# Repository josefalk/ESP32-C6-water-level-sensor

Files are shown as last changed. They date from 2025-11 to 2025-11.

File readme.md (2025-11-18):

# ESP32-C6 Water Level Monitoring System

Ultrasonic tank-level monitor with 
**A02YYUW sensor**, **SSD1306 OLED**, 
and **NeoPixel RGB LED**, 
featuring WiFi setup and live web dashboard.

##  Features
- **A02YYUW ultrasonic distance sensor** (UART)
- **SSD1306 OLED display** (I²C) for live readings
- **NeoPixel RGB LED** status indicator
- **WiFi setup portal** (AP/STA modes)
- Configurable **full** and **empty** tank distances
- Modular C++/ESP32 code

##  Project Structure

esp32-distance-sensor/
├── README.md
├── main/
│ ├── main.py # Main application
│ ├── A02YYUW.h / A02YYUW.cpp # Ultrasonic sensor driver
│ ├── user-led.h / user-led.cpp # NeoPixel LED control
│ ├── user-screen.h / user-screen.cpp # OLED display module
│ └── user-wifi.h / user-wifi.cpp # WiFi & web server
└── Libraries/
└── ...

##  Wiring

### A02YYUW → ESP32-C6

| Sensor Wire | ESP32-C6 Pin |
|---|---|
| Red (5V) | 5V |
| Black (GND) | GND |
| White (TX)  | GPIO 4 |
| Yellow (RX) | GPIO 5 |

| Sensor Wire | 2 pair cable | DC Barrel Jack | ESP32-C6 Pin |
|---|---|---|---|
| Red (5V) | orange | Red | 5V |
| Black (GND) | brown | Black | GND |
| White (TX)  | blue | Black | GPIO 4 |
| Yellow (RX) | green | Red | GPIO 5 |

### OLED (SSD1306) → ESP32-C6

| OLED Pin | ESP32-C6 Pin |
|---|---|
| VCC | 3.3V |
| GND | GND |
| SDA | GPIO 3 |
| SCL | GPIO 2 |

### NeoPixel LED → ESP32-C6

| LED Pin | ESP32-C6 Pin |
|---|---|
| Data In | GPIO 8 |
| VCC | 5V |
| GND | GND |

### Button → ESP32-C6

| Button Pin | ESP32-C6 Pin |
|---|---|
| One side | GPIO 18 |
| Other side | GND |

---

## ESP32-C6  Connections

| Source | Destination |
|---|---|
| 5V | A02YYUW RED |
| GND | A02YYUW BLACK |
| GND | SSD1306 GND |
| GND | BUTTON 1 |
| GND | BUTTON 2 |
| 3.3V | SSD1306 VCC |
| GPIO 0 | BUTTON |
| GPIO 3 | SSD1306 I2C_SDA |
| GPIO 2 | SSD1306 I2C_SCL |
| GPIO 4 | A02YYUW White |
| GPIO 5 | A02YYUW Yellow |
| GPIO 18 | BUTTON 2 LARGE |

## Screen shot of Webserver:

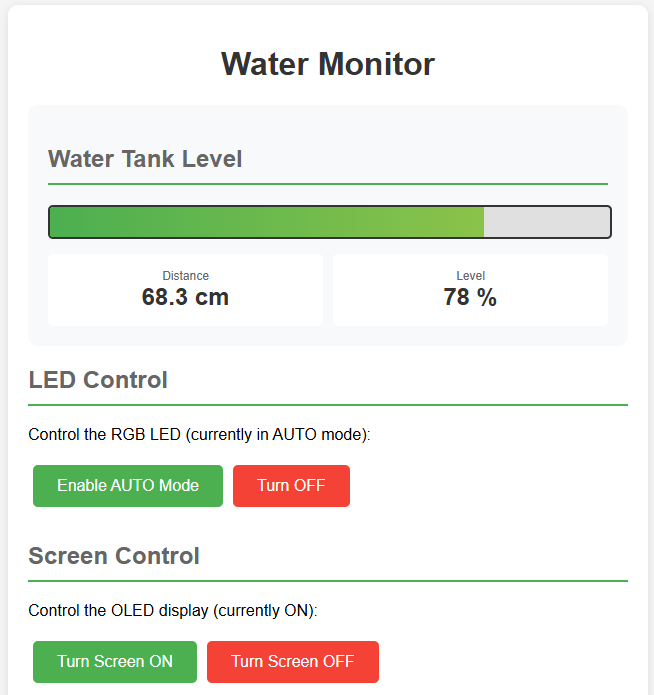
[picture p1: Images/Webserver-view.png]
Webserver-view


 ## Photos:

 
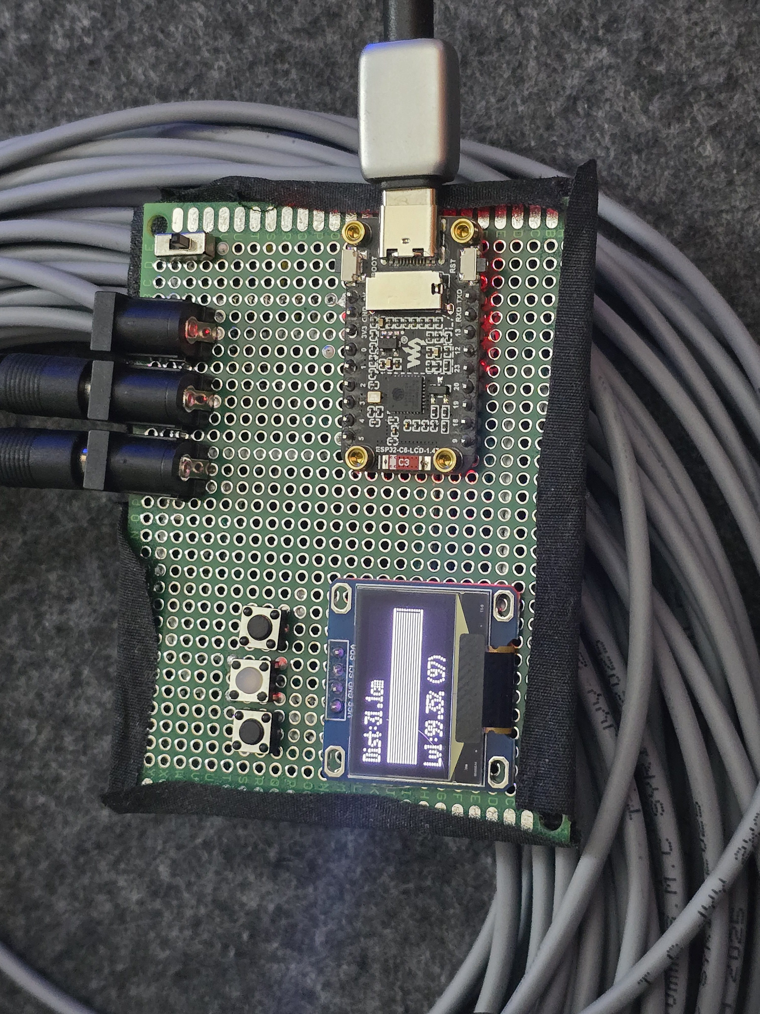
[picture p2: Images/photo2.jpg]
 

## don't forget to turn on UART Serial.
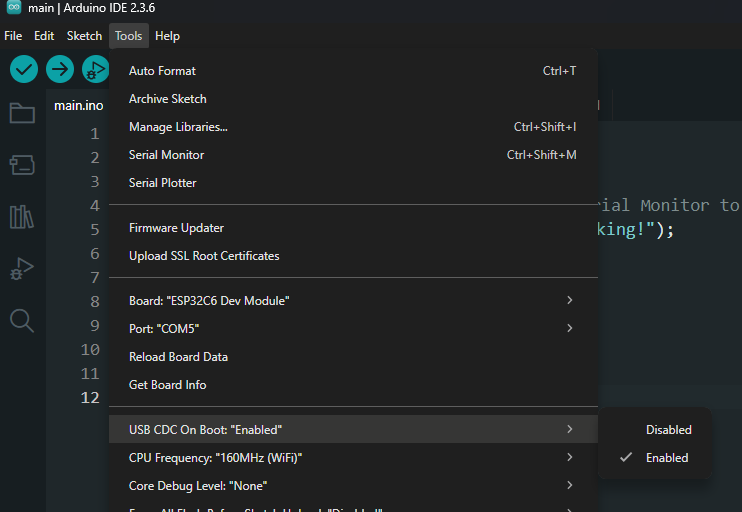
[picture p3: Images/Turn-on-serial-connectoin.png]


## ⚙️ Other Details

- **Cable**: 2-pair, 30 meters
- **DC Inputs**:
  1. 5V power input
  2. RX/TX for UART communication
  3. 5V output to sensor
- **Buttons**:
  - **Power switch**: Turns the device on/off
  - **Screen toggle button**: Turns OLED display on/off
  - **WiFi reset button**: Hold 3 seconds to clear WiFi credentials
  - **Extra button (future use)**: Could be used to control LED or other features

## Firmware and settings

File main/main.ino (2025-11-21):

// ============================================
//  main.ino
// ============================================

#include "user-led.h"      // LED control (manual/auto modes + RGB output)
#include "user-screen.h"   // OLED display + button handling
#include "user-wifi.h"     // Wi-Fi manager + web server update functions
#include "A02YYUW.h"       // Ultrasonic distance sensor driver

HardwareSerial mySerial(2);           // Use UART2 for the A02YYUW sensor
A02YYUW sensor(mySerial, 4, 5);       // RX=4, TX=5 (sensor uses serial)

void setup() {
  Serial.begin(115200);     // Debug output
  sensor.begin(9600);       // A02YYUW baud rate

  initLED();                // Prepare RGB LED / WS2812
  initScreen();             // Initialize OLED and UI
  initWiFi();               // Start Wi-Fi AP/STA + web server (loads distances from preferences)

  showText("System Ready!"); // Show startup message
}

void loop() {
  handleWiFi();             // Process Wi-Fi events + web requests
  handleScreenButton();     // Check button input for screen navigation

  float distance = sensor.getDistance();   // Read ultrasonic sensor value (cm)

  if (distance > 0) {       // Valid reading
    Serial.printf("Distance: %.1f cm\n", distance);

    // Get current calibration values (always use live values from preferences)
    float fullDist = getFullDistance();
    float emptyDist = getEmptyDistance();

    // Convert raw distance to percentage (0–100%)
    float percent = (emptyDist - distance) /
                    (emptyDist - fullDist) * 100;
    percent = constrain(percent, 0, 100);

    updateSensorData(distance, percent);   // Expose values to web UI

    showWaterLevel(distance,               // Draw tank level on screen
                    fullDist,
                    emptyDist);

    // Auto LED color logic (only if auto mode is enabled)
    if (isLedAutoMode()) {
      if (percent < 20)       ledOn(255, 0, 0);   // Low → Red
      else if (percent < 70)  ledOn(255, 255, 0); // Medium → Yellow
      else                    ledOn(0, 255, 0);   // High → Green
    }

  } else {
    // Sensor returned an invalid value
    showText("No reading");
    
    if (isLedAutoMode())
      ledOn(255, 0, 0);       // Show alert state

    updateSensorData(0, 0);   // Push "invalid" state to the web UI
  }

  delay(500);                 // Fixed sampling interval
}

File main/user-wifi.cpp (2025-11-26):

// ============================================
// user-wifi.cpp
// ============================================
#include "user-wifi.h"
#include "user-led.h"
#include "user-screen.h"
#include <WiFi.h>
#include <WebServer.h>
#include <Preferences.h>

// Access Point credentials
const char* ap_ssid = "ESP32-Config";
const char* ap_password = "";

// Create web server on port 80
WebServer server(80);
Preferences preferences;

// Variables
int ledState = LOW;
const int RESET_BUTTON_PIN = 0;
unsigned long buttonPressStart = 0;
bool buttonPressed = false;
bool isAPMode = true;
void setLedAutoMode(bool state);
bool getScreenState();
void setScreenState(bool state);
void handleLed();
void handleScreen();

// Sensor data variables
float currentDistance = 0.0;
float currentPercent = 0.0;
bool sensorDataValid = false;

// Calibration values (defaults)
float fullDistance = 30.0;
float emptyDistance = 200.0;

// Forward declarations
void checkResetButton();
void connectToWiFi(const char* ssid, const char* password);
void startAPMode();
void handleRoot();
void handleScan();
void handleConnect();
void handleLedOn();
void handleLedOff();
void handleStatus();
void handleData();
void handleScreenOn();
void handleScreenOff();
void handleCalibration();
void handleGetCalibration();
void handleNotFound();

float getFullDistance() {
  return fullDistance;
}

float getEmptyDistance() {
  return emptyDistance;
}

void setCalibration(float full, float empty) {
  fullDistance = full;
  emptyDistance = empty;
  preferences.putFloat("fullDist", full);
  preferences.putFloat("emptyDist", empty);
  Serial.printf("Calibration saved: Full=%.1f cm, Empty=%.1f cm\n", full, empty);
}

void initWiFi() {
  pinMode(RESET_BUTTON_PIN, INPUT_PULLUP);
  
  preferences.begin("wifi", false);
  
  // Load calibration values or use defaults
  fullDistance = preferences.getFloat("fullDist", 30.0);
  emptyDistance = preferences.getFloat("emptyDist", 200.0);
  Serial.printf("Loaded calibration: Full=%.1f cm, Empty=%.1f cm\n", fullDistance, emptyDistance);
  
  String ssid = preferences.getString("ssid", "");
  String password = preferences.getString("password", "");
  
  if (ssid.length() > 0) {
    Serial.println("Attempting to connect to saved WiFi...");
    connectToWiFi(ssid.c_str(), password.c_str());
  } else {
    Serial.println("No saved WiFi credentials. Starting AP mode...");
    startAPMode();
  }
  server.on("/led", handleLed);
  server.on("/screen", handleScreen);
  server.on("/", handleRoot);
  server.on("/scan", handleScan);
  server.on("/connect", HTTP_POST, handleConnect);
  server.on("/status", handleStatus);
  server.on("/data", handleData);
  server.on("/calibration", HTTP_POST, handleCalibration);
  server.on("/calibration", HTTP_GET, handleGetCalibration);
  server.onNotFound(handleNotFound);
  
  server.begin();
  Serial.println("HTTP server started");
}

void handleWiFi() {
  server.handleClient();
  checkResetButton();
}

bool isWiFiConnected() {
  return !isAPMode && WiFi.status() == WL_CONNECTED;
}

String getWiFiIP() {
  if (isAPMode) {
    return WiFi.softAPIP().toString();
  } else {
    return WiFi.localIP().toString();
  }
}

bool isLedAutoMode() {
  return ledAutoMode;
}

void updateSensorData(float distance, float percent) {
  currentDistance = distance;
  currentPercent = percent;
  sensorDataValid = true;
}

void checkResetButton() {
  int buttonState = digitalRead(RESET_BUTTON_PIN);
  
  if (buttonState == LOW && !buttonPressed) {
    buttonPressed = true;
    buttonPressStart = millis();
    Serial.println("WiFi reset button pressed...");
  } else if (buttonState == LOW && buttonPressed) {
    unsigned long pressDuration = millis() - buttonPressStart;
    
    if (pressDuration >= 3000) {
      Serial.println("Reset button held for 3 seconds!");
      Serial.println("Clearing WiFi credentials and restarting in AP mode...");
      
      ledOn(255, 0, 0);
      delay(500);
      ledOff();
      delay(200);
      ledOn(255, 0, 0);
      delay(500);
      ledOff();
      
      preferences.clear();
      preferences.end();
      
      Serial.println("Restarting...");
      delay(500);
      
      ESP.restart();
    }
  } else if (buttonState == HIGH && buttonPressed) {
    unsigned long pressDuration = millis() - buttonPressStart;
    Serial.printf("Button released after %lu ms\n", pressDuration);
    buttonPressed = false;
  }
}

void connectToWiFi(const char* ssid, const char* password) {
  Serial.print("Connecting to WiFi: ");
  Serial.println(ssid);
  
  WiFi.mode(WIFI_STA);
  WiFi.begin(ssid, password);
  
  int attempts = 0;
  while (WiFi.status() != WL_CONNECTED && attempts < 20) {
    delay(500);
    Serial.print(".");
    ledOn(0, 0, 255);
    delay(100);
    ledOff();
    attempts++;
  }
  
  if (WiFi.status() == WL_CONNECTED) {
    Serial.println();
    Serial.println("WiFi connected successfully!");
    Serial.print("IP address: ");
    Serial.println(WiFi.localIP());
    isAPMode = false;
    
    ledOn(0, 255, 0);
    delay(1000);
    ledOff();
  } else {
    Serial.println();
    Serial.println("Failed to connect to WiFi");
    Serial.println("Starting AP mode for configuration...");
    startAPMode();
  }
}

void startAPMode() {
  WiFi.mode(WIFI_AP);
  WiFi.softAP(ap_ssid, ap_password);
  
  Serial.println("=============================");
  Serial.println("AP Mode Started");
  Serial.println("=============================");
  Serial.print("SSID: ");
  Serial.println(ap_ssid);
  Serial.print("IP Address: ");
  Serial.println(WiFi.softAPIP());
  Serial.println("Connect to this network and");
  Serial.println("go to http://192.168.4.1");
  Serial.println("=============================");
  
  isAPMode = true;
  
  ledOn(128, 0, 128);
  delay(500);
  ledOff();
}
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

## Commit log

2025-11-21 Added calibration section in the user's web interfact for empty and full tank distance
2025-11-26 update toggle led and screen from web
2025-12-07 making a drawing
    [water-level-sensor-drawing.fzz]
